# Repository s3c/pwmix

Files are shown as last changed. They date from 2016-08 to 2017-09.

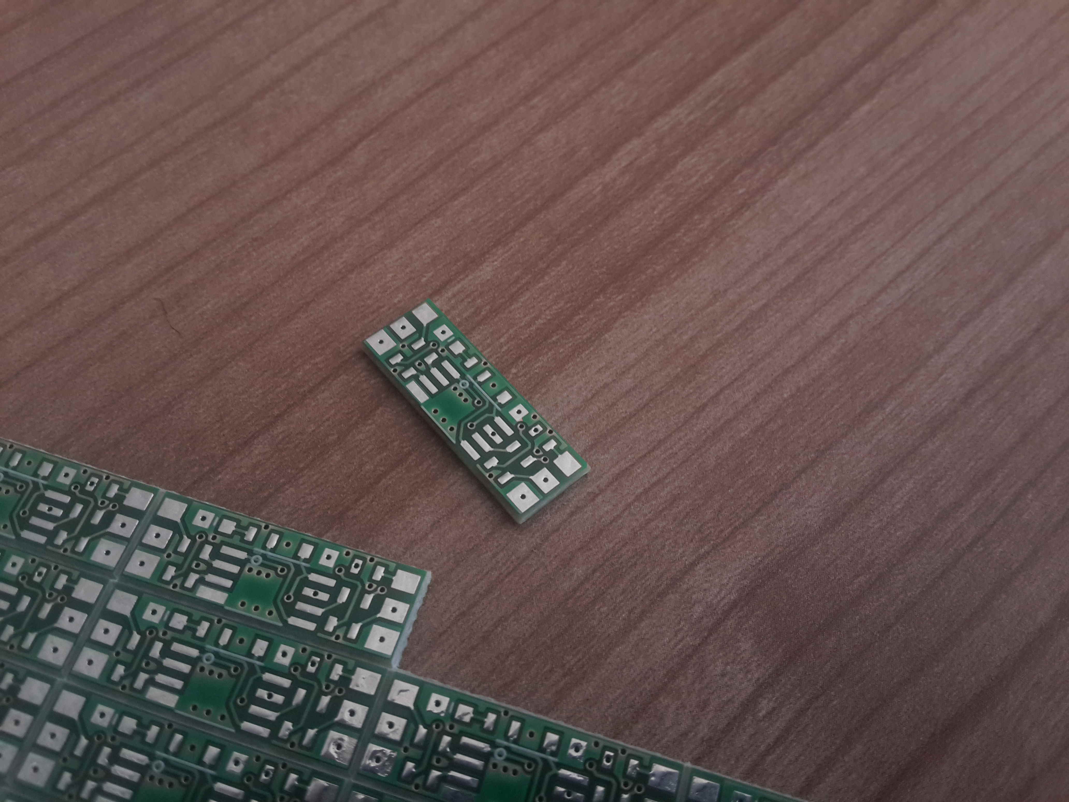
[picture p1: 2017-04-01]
pictures/IMG_20160907_095543.jpg

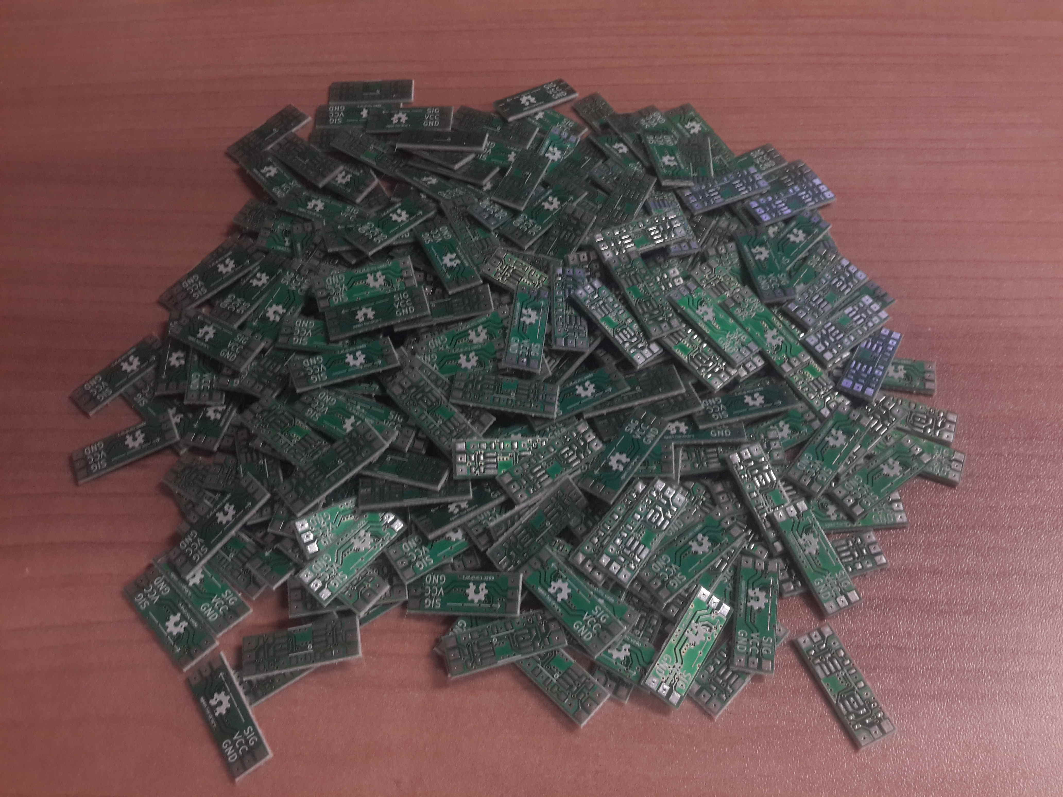
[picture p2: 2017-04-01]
pictures/IMG_20160907_113401.jpg

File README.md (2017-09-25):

The pwmix project is a small hardware device that can alter PWM/PPM signals generated by common hobby remote controls. This allows enabling mixing for cheap RC transmitters, or where the receiver applies some mechanism that isn't desired. It is based on the Attiny85 but smaller micro controllers like the Attiny25 can  be used, you'll need a pretty steady hand to make it fit on the edge of the larger footprint though. 

The unit supports two inputs and two outputs, although these are identical and can potentially be used otherwise. With the micro controller facing upwards, the top left channel is input channel one, the bottom left channel is input two, the bottom right channel is output one, and the top right channel is output two. By convention, input one is considered the main input, and input two is considered the modulating input.

Since the Attiny85 has an inaccurate internal timer, rather than adding a crystal the unit does a clock sync to sync with the receiver. This is done by adjusting the internal clock using a binary search at startup, to match the expected pulse length with what is received. This is done on input channel one, and the expected value differs between code features.

The project was created with the following in mind:

* (DONE) Differential drive mixing - the main input takes a motor drive, while the second takes a servo turning signal. These are mixed together to output two motor drive signals mixed to provide differential drive. This allows the use of two motors to drive and steer, as opposed to a motor and a servo. Initial sync should be at mid stick (1.5mS PWM pulse)
* Servo limiting (planned) - the main input takes a servo input, while the optional second input takes a calibration servo signal. If the second signal is present, the minimum and maximum values are stored and saved in EEPROM. The output signals are mirrored and will never exeed the stored limits. To set the limits plug in both signals and vary the second signal between min/max. The input signal is scaled so full input deflection gives full limited output deflection. Initial sync should be at low stick (1mS PWM pulse)
* Fake Nitrous oxide (planned) - the main input takes a motor drive, while the second takes a enable signal. If the enable signal is greater than 3/4 full deflection, the mirrored outputs (following the motor drive signal) are allowed to swing to greater than 50%, if not, the output signals are limited to 50%. When this enable trigger is active, a timer decrements a 30 second limit, which limits the motor to 50% when depleted. This creates a fake boost mechanism, which gives a more dynamic nature to racing. Initial sync should be at mid stick (1.5mS PWM pulse)
* (DONE) PPM to PWM converter - Each board strips off the first two PPM channels and outputs them as PWM, then passes the remaining PPM signal along. This allows daisy chaining the PPM signal along the body of the plane so you only need to run one wire from the receiver and still be able to control all servos/motors, etc.

Known issues (Differential drive mixing):
* There seems to be a dead band/jitter of around 50uS for small values on input two in one direction, this also seems to reflect more on output one than output two for some reason. I don't really know why this is happening, I've confirmed that there is a tiny dead band/jitter on the input channel, but insignificant compared to the output. The inputs/outputs aren't handled differently in any way so some weird race condition is in play here. The most likely scenario is that the edge trigger interrupt fires just before the compare match timer, so the timer interrupt only fires after the edge has been processed, creating a dead band region. The ideal fix for this would be to use the compare match module to automatically turn off the output pins, but the hardware doesn't allow this, as the output pins aren't assigned to the compare match pins. I'll fix this if there's ever another revision. **Update: Ok, I managed to confirm that this was the problem, and I fixed the issue by making the pin change ISR non-blocking and adding a flag to avoid re-entry if another pin change occured. We still have some jitter but that's to be expected considering all the overhead and no crystal. The above fix would still be better though**

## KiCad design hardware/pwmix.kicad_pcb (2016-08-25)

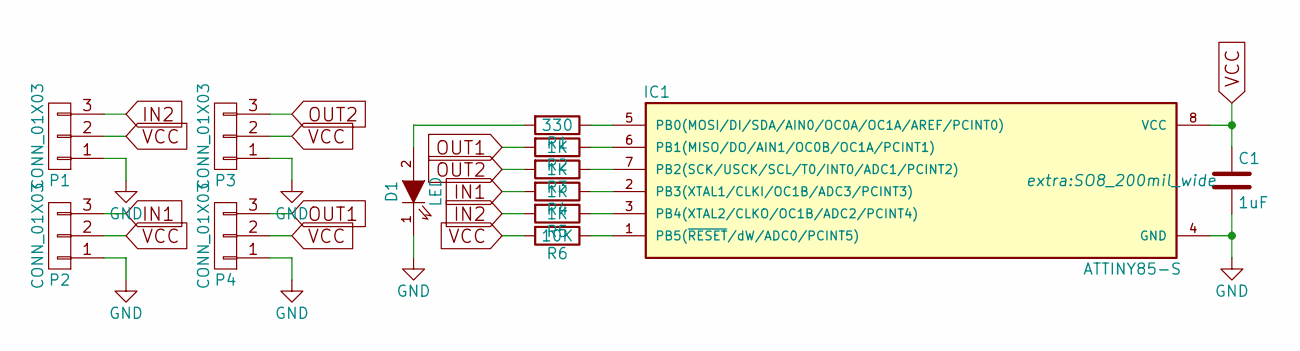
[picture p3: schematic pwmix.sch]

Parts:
C1: 1uF; C_0805
D1: LED; LED_0805
IC1: ATTINY85-S; SO8_200mil_wide
P1, P2, P3, P4: CONN_01X03; Pin_Header_Angled_1x03
R1: 330; R_0805
R2, R3, R4, R5: 1K; R_0805
R6: 10K; R_0805

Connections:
GND: C1.2, D1.1 (K), IC1.4 (GND), P1.1, P2.1, P3.1, P4.1
IN1: P2.3, R4.2
IN2: P1.3, R5.2
unnamed: D1.2 (A), R1.2
unnamed: IC1.1 (PB5(~RESET~/dW/ADC0/PCINT5)), R6.1
unnamed: IC1.2 (PB3(XTAL1/CLKI/OC1B/ADC3/PCINT3)), R4.1
unnamed: IC1.3 (PB4(XTAL2/CLKO/OC1B/ADC2/PCINT4)), R5.1
unnamed: IC1.5 (PB0(MOSI/DI/SDA/AIN0/OC0A/OC1A/AREF/PCI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), R1.1
unnamed: IC1.6 (PB1(MISO/DO/AIN1/OC0B/OC1A/PCINT1)), R2.1
unnamed: IC1.7 (PB2(SCK/USCK/SCL/T0/INT0/ADC1/PCINT2)), R3.1
OUT1: P4.3, R2.2
OUT2: P3.3, R3.2
VCC: C1.1, IC1.8 (VCC), P1.2, P2.2, P3.2, P4.2, R6.2

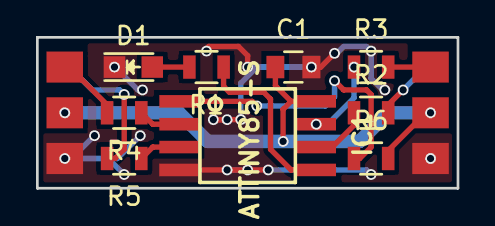
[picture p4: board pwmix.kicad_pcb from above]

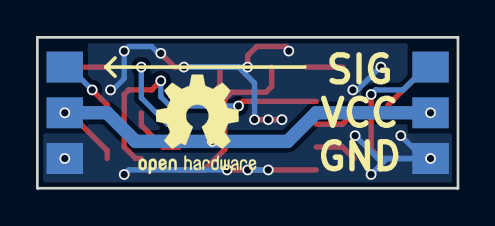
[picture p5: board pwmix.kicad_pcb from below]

Board: 2 copper layers, 23.4 x 8.4 mm, 13 parts (2 on the bottom side), 13 nets.

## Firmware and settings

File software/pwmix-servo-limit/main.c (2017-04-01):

/*
 * pwmix2.c
 *
 * Created: 9/10/2016 7:29:07 AM
 * Author : User
 */ 

//Prog
//3 - Aux	->	Ch1
//2 - Th	->	Ch2
//1 - St	->	NC

//Use
//3 - Aux	->	Ch1
//2 - Th	->	NC
//1 - St	->	NC

#define F_CPU 8000000UL

#include <avr/io.h>
#include <avr/interrupt.h>
#include <util/delay.h>
#include <avr/eeprom.h>
#include "main.h"

volatile int16_t lastPulseValI16A[2]; //Stores the last pulse received for each channel
volatile int16_t mixPulseValI16A[2]; //Stores the output pulse after mixing
volatile uint8_t inputStateUI8A[2]; //Stores the state of each channel
volatile uint8_t minServoValUI8; //Minimum value servo is allowed to take
volatile uint8_t maxServoValUI8; //Maximum value servo is allowed to take
volatile uint8_t saveCounterUI8; //Prohibit saving until this counter reaches certain value
volatile uint8_t flagsUI8; //Stores sync flags 

ISR(TIM0_COMPA_vect){ //Turn off channel one output on compare match, have to do this manually since the pins weren't assigned correctly
	PORTB &= ~_BV(OUT_CHANNEL_ONE);
}

ISR(TIM1_COMPA_vect){ //Turn off channel two output on compare match, have to do this manually since the pins weren't assigned correctly
	PORTB &= ~_BV(OUT_CHANNEL_TWO);
}

void saveControl(void){
	//Todo: if in config mode, both channels are idle, new boundary received, and save counter is high enough, save and pulse led, reset counter and flags
	
	if((flagsUI8 & FLAGS_CH_TWO_RECV) && (inputStateUI8A[CHANNEL_ONE] == STATE_IDLE) && (inputStateUI8A[CHANNEL_TWO] == STATE_IDLE)){
		
		
	}
}

ISR(TIM0_OVF_vect){
	//flagsUI8 |= FLAGS_CH_ONE_RECV;
	if(inputStateUI8A[CHANNEL_ONE] == STATE_ACTIVE) //If we had an overflow before the pulse ended
		lastPulseValI16A[CHANNEL_ONE] = PWM_MAX; //Just save the value as longest valid pulse length
	inputStateUI8A[CHANNEL_ONE] = STATE_IDLE;
	PORTB &= ~_BV(OUT_CHANNEL_ONE); //Should never be needed
	TCCR0B = 0; //Disable TIMR0
	saveControl(); //Check this for both input channels, since we don't want to cause an EEPROM write lock while input is active
}

ISR(TIM1_OVF_vect){
	//flagsUI8 |= FLAGS_CH_TWO_RECV;
	if(inputStateUI8A[CHANNEL_TWO] == STATE_ACTIVE) //If we had an overflow before the pulse ended
		lastPulseValI16A[CHANNEL_TWO] = PWM_MAX; //Just save the value as longest valid pulse length
	inputStateUI8A[CHANNEL_TWO] = STATE_IDLE;
	PORTB &= ~_BV(OUT_CHANNEL_TWO); //Should never be needed
	TCCR1 = 0; //Disable TIMR1
	saveControl(); //Check this for both input channels, since we don't want to cause an EEPROM write lock while input is active
}

ISR(PCINT0_vect, ISR_NOBLOCK){ //Executed in input pin change
	uint8_t channelVarUI8, channelTmpUI8;
	
	if(flagsUI8 & FLAGS_PIN_CHANGE)
		return;
	flagsUI8 |= FLAGS_PIN_CHANGE;
	
	for(channelVarUI8 = CHANNEL_ONE; channelVarUI8 <= CHANNEL_TWO; channelVarUI8++){ //Check both input channels, since pin change int doesn't tell us which pin changed
		switch(inputStateUI8A[channelVarUI8]){
			case STATE_IDLE:
				if(PINB & _BV((channelVarUI8 == CHANNEL_ONE)?IN_CHANNEL_ONE:IN_CHANNEL_TWO)){ //If state idle and input signal high
					inputStateUI8A[channelVarUI8] = STATE_ACTIVE;
					if(flagsUI8 & FLAGS_CH_TWO_RECV){ //if sync mode output current ch2 value
						mixPulseValI16A[CHANNEL_ONE] = lastPulseValI16A[CHANNEL_TWO];
						mixPulseValI16A[CHANNEL_TWO] = PWM_MIDDLE - (PWM_MIDDLE - lastPulseValI16A[CHANNEL_TWO]);
					}else{ //if normal mode, scale max output to ch2 presets
						mixPulseValI16A[CHANNEL_ONE] = lastPulseValI16A[CHANNEL_ONE];
						mixPulseValI16A[CHANNEL_TWO] = PWM_MIDDLE - (PWM_MIDDLE - lastPulseValI16A[CHANNEL_ONE]);
					}
					for(channelTmpUI8 = CHANNEL_ONE; channelTmpUI8 <= CHANNEL_TWO; channelTmpUI8++){ //Make sure the mixed values are within reasonable limits
						if(mixPulseValI16A[channelTmpUI8] > maxServoValUI8)
							mixPulseValI16A[channelTmpUI8] = maxServoValUI8;
						if(mixPulseValI16A[channelTmpUI8] < minServoValUI8)
							mixPulseValI16A[channelTmpUI8] = minServoValUI8;
					}
					if(channelVarUI8 == CHANNEL_ONE){
						OCR0A = mixPulseValI16A[CHANNEL_ONE]; //Set compare match to stop output pulse
						TCNT0 = 0; //Reset TMR0 				
						GTCCR |= _BV(PSR0); //Reset TMR0 prescaler
						TCCR0B |= _BV(CS01) | _BV(CS00); //Start TMR0 with 64 prescaler
						if(flagsUI8 & FLAGS_SYNC_DONE)
							PORTB |= _BV(OUT_CHANNEL_ONE); //Set channel output high
					}else{
						OCR1A = mixPulseValI16A[CHANNEL_TWO]; //Set compare match to stop output pulse
						TCNT1 = 0; //Reset TMR1 
						GTCCR |= _BV(PSR1); //Reset TMR1 prescaler
						TCCR1 |= _BV(CS12) | _BV(CS11) | _BV(CS10); //Start TMR1 with 64 prescaler
						if(flagsUI8 & FLAGS_SYNC_DONE)
							PORTB |= _BV(OUT_CHANNEL_TWO); //Set channel output high
					}
				}
				break;
			case STATE_ACTIVE:
				if(!(PINB & _BV((channelVarUI8 == CHANNEL_ONE)?IN_CHANNEL_ONE:IN_CHANNEL_TWO))){ //If state active and input signal low
					inputStateUI8A[channelVarUI8] = STATE_IDLE;
					if(channelVarUI8 == CHANNEL_ONE){
						lastPulseValI16A[CHANNEL_ONE] = TCNT0; //Save the length of last pulse
						flagsUI8 |= FLAGS_CH_ONE_RECV; //Mark that we received a new pulse (for sync)
					}else{
						lastPulseValI16A[CHANNEL_TWO] = TCNT1; //Save the length of last pulse
						flagsUI8 |= FLAGS_CH_TWO_RECV; //Mark that we received a new pulse (for sync)
						if(flagsUI8 & FLAGS_SYNC_DONE){
							if(lastPulseValI16A[CHANNEL_TWO] < minServoValUI8){
								minServoValUI8 = lastPulseValI16A[CHANNEL_TWO];
								flagsUI8 |= FLAGS_LIMIT_CHANGE;
								saveCounterUI8 = 0;
							}else if(lastPulseValI16A[CHANNEL_TWO] > maxServoValUI8){
								maxServoValUI8 = lastPulseValI16A[CHANNEL_TWO];
								flagsUI8 |= FLAGS_LIMIT_CHANGE;
								saveCounterUI8 = 0; 
							}else if(saveCounterUI8 < LIMIT_CHANGE_SAVE)
									saveCounterUI8++;
						}
					}
				}
				break;
		}
	}
	
	flagsUI8 &= ~FLAGS_PIN_CHANGE;
}

void inline waitNextPulse(void){
	flagsUI8 &= ~FLAGS_CH_ONE_RECV; //First pulse might be incomplete do to changing clock mid pulse, so disregard
	while(!(flagsUI8 & FLAGS_CH_ONE_RECV)); //Wait till we have a new pulse length
	flagsUI8 &= ~FLAGS_CH_ONE_RECV; //Redo and get a valid pulse length
	while(!(flagsUI8 & FLAGS_CH_ONE_RECV)); //Wait till pulse is done
}

void clockSync(void){ //Sync clock to receiver, assuming first couple of pulses from receiver is at mid stick, ie, 1.5mS
	int16_t curDevI16, minDevI16 = INT16_MAX;
	uint8_t stepValueUI8 = 64, trialValueUI8 = _BV(7), minTrialValueUI8 = UINT8_MAX, tmpTrialValueUI8;
	
	do{ //Binary search over 7 bits of OSCCAL, bit 7 is high range bit so we skip it
		OSCCAL = trialValueUI8 + stepValueUI8;
		waitNextPulse();
		if(lastPulseValI16A[CHANNEL_ONE] < PWM_SYNC)
			trialValueUI8 += stepValueUI8;
		stepValueUI8 >>= 1;
	}while(stepValueUI8);
	
	for(tmpTrialValueUI8 = trialValueUI8 - 1; tmpTrialValueUI8 <= trialValueUI8 + 1; tmpTrialValueUI8++){ //Local search to identify closest match
		OSCCAL = tmpTrialValueUI8;
		waitNextPulse();
		curDevI16 = abs(lastPulseValI16A[CHANNEL_ONE] - PWM_SYNC);
		if(curDevI16 < minDevI16){
			minDevI16 = curDevI16;
			minTrialValueUI8 = tmpTrialValueUI8;
		}
	}

	OSCCAL = minTrialValueUI8; //Set closest clock value
	flagsUI8 |= FLAGS_SYNC_DONE; //Set sync as complete, so output module can start generating pulses
	PORTB |= _BV(OUT_CHANNEL_LED); //Turn on LED to notify setup complete
}

void loadSavedLimits(void){
	
	minServoValUI8 = eeprom_read_byte(EEPROM_ADDR_MIN);
	maxServoValUI8 = eeprom_read_byte(EEPROM_ADDR_MAX);
	
	if(minServoValUI8 == 0xFF || maxServoValUI8 == 0xFF){
		minServoValUI8 = PWM_MIN;
		maxServoValUI8 = PWM_MAX;
	}
}

void saveNewLimits(void){
	eeprom_write_byte(EEPROM_ADDR_MIN, minServoValUI8);
	eeprom_write_byte(EEPROM_ADDR_MAX, maxServoValUI8);
}

void init(void){
	
	DDRB |= _BV(OUT_CHANNEL_ONE) | _BV(OUT_CHANNEL_TWO) | _BV(OUT_CHANNEL_LED); //Set output channels as outputs
	PORTB |= _BV(IN_CHANNEL_ONE) | _BV(IN_CHANNEL_TWO); //Enable pull-ups for input channels
	
	lastPulseValI16A[CHANNEL_ONE] = lastPulseValI16A[CHANNEL_TWO] = PWM_MAX+1; //Clear last pules length values initially
	mixPulseValI16A[CHANNEL_ONE] = mixPulseValI16A[CHANNEL_TWO] = PWM_MIDDLE; //Set initial mixing output values
	inputStateUI8A[CHANNEL_ONE] = inputStateUI8A[CHANNEL_TWO] = STATE_IDLE; //Set start states to idle
	flagsUI8 = FLAGS_NONE; //Blank initial flags
	
	TIMSK |= _BV(OCIE0A) | _BV(TOIE0) | _BV(OCIE1A) | _BV(TOIE1); //TMR0/1 Interrupt on compare match and overflow
	
	PCMSK |= _BV(IN_CHANNEL_ONE) | _BV(IN_CHANNEL_TWO); //Enable pin change interrupts on input pins
	GIMSK |= _BV(PCIE); //Enable pin change interrupts globally
	
	sei();
}

int main(void){
	
	_delay_ms(100); //Allow everything to start up
	
	init(); //Initialize all peripherals and variables
	clockSync(); //Perform the clock sync, as INT RC OSC is pretty crap, assume receiver is correct

	if(flagsUI8 & FLAGS_CH_TWO_RECV)
		minServoValUI8 = maxServoValUI8 = PWM_MIDDLE;
	else
		loadSavedLimits();

	while(1){

	}
}

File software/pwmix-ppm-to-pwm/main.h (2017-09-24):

/*
 * main.h
 *
 * Created: 9/8/2016 4:50:35 AM
 *  Author: User
 */ 

#ifndef MAIN_H_
#define MAIN_H_

#define STATE_IDLE				0
#define STATE_WAIT				1
#define STATE_PULSE_1_START		2
#define STATE_PULSE_1_MID		3
#define STATE_PULSE_2_START		4
#define STATE_PULSE_2_MID		5

#define IN_CHANNEL_PPM			PB3

#define OUT_CHANNEL_ONE			PB1
#define OUT_CHANNEL_TWO			PB2
#define OUT_CHANNEL_LED			PB0
#define OUT_CHANNEL_PPM			PB4

#endif /* MAIN_H_ */

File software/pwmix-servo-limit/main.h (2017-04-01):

/*
 * main.h
 *
 * Created: 9/8/2016 4:50:35 AM
 *  Author: User
 */ 

#ifndef MAIN_H_
#define MAIN_H_

#include <avr/io.h>

#define abs(x) (((x)>0)?(x):(-x))

#define FLAGS_NONE			0
#define FLAGS_CH_ONE_RECV   1
#define FLAGS_CH_TWO_RECV   2
#define FLAGS_SYNC_DONE		4
#define FLAGS_PIN_CHANGE	8
#define FLAGS_PROG_nNORM	16
#define FLAGS_LIMIT_CHANGE	32
#define FLAGS_PULSE_LED		64

#define CHANNEL_ONE			0
#define CHANNEL_TWO			1

#define PWM_MIN				125
#define PWM_MIDDLE			188
#define PWM_MAX				250
#define PWM_SYNC			PWM_MIN

#define LIMIT_CHANGE_SAVE	50

#define STATE_IDLE			0
#define STATE_ACTIVE		1

#define EEPROM_ADDR_MIN		(uint8_t *) 0
#define EEPROM_ADDR_MAX		(uint8_t *) 1

#define IN_CHANNEL_ONE		PB3
#define IN_CHANNEL_TWO		PB4

#define OUT_CHANNEL_ONE		PB1
#define OUT_CHANNEL_TWO		PB2
#define OUT_CHANNEL_LED		PB0

#endif /* MAIN_H_ */

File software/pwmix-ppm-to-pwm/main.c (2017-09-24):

/*
 * pwmix2.c
 *
 * Created: 9/10/2016 7:29:07 AM
 * Author : User
 */ 

#define F_CPU 8000000UL

#include <avr/io.h>
#include <avr/interrupt.h>
#include "main.h"

volatile uint8_t systemStateUI8; //Stores the current state

void copy_output_input(void){
	if(PINB & _BV(IN_CHANNEL_PPM))
		PORTB |= _BV(OUT_CHANNEL_PPM);
	else
		PORTB &= ~_BV(OUT_CHANNEL_PPM);
}


ISR(TIM1_OVF_vect){
	systemStateUI8 = STATE_WAIT;
	PORTB ^= _BV(OUT_CHANNEL_LED);
	TCCR1 = 0; //Disable TMR1
}

ISR(PCINT0_vect){

	TCNT1 = 0; //Reset TMR1
	GTCCR |= _BV(PSR1); //Reset TMR1 prescaler

	switch(systemStateUI8){
		case(STATE_IDLE):
			copy_output_input();
			break;
		case(STATE_WAIT):
			systemStateUI8 = STATE_PULSE_1_START;
			PORTB |= _BV(OUT_CHANNEL_ONE);
			break;
		case(STATE_PULSE_1_START):
			systemStateUI8 = STATE_PULSE_1_MID;
			break;
		case(STATE_PULSE_1_MID):
			systemStateUI8 = STATE_PULSE_2_START;
			PORTB &= ~_BV(OUT_CHANNEL_ONE);
			PORTB |= _BV(OUT_CHANNEL_TWO);
			break;
		case(STATE_PULSE_2_START):
			systemStateUI8 = STATE_PULSE_2_MID;
			break;
		case(STATE_PULSE_2_MID):
			systemStateUI8 = STATE_IDLE;
			PORTB &= ~_BV(OUT_CHANNEL_TWO);
			copy_output_input();
			TCCR1 |= _BV(CS13); //TMR1 128 prescaler
			break;
	}
}

void init(void){
	
	systemStateUI8 = STATE_IDLE; //Set start state to idle
	
	DDRB |= _BV(OUT_CHANNEL_PPM) | _BV(OUT_CHANNEL_ONE) | _BV(OUT_CHANNEL_TWO) | _BV(OUT_CHANNEL_LED); //Set output channels as outputs
	PORTB |= _BV(IN_CHANNEL_PPM); //Enable pull-ups for input channel
	copy_output_input();
	
	TIMSK |= _BV(TOIE1); //TMR1 Interrupt on overflow
	TCCR1 |= _BV(CS13); //TMR1 128 prescaler
	
	PCMSK |= _BV(IN_CHANNEL_PPM); //Enable pin change interrupts on input pin
	GIMSK |= _BV(PCIE); //Enable pin change interrupts globally
	
	sei();
}

int main(void){
	
	init(); //Initialize all peripherals and variables

	while(1){}
}

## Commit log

2016-08-24 Redid layout, as attiny85 footprint in kicad is way too small
    [pwmix.drl, pwmix.gbl, pwmix.gbo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]
2016-08-25 Regenerated and submitted gerbers
    [pwmix.kicad_pcb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]
2016-09-11 First version fail, clock accuracy issues, going to redo with sync
    [main.c, main.h]
2016-09-11 Jitter is way better now, was a rounding error and unsigned to signed conversion, still some jitter on the one channel, which makes no sense since they should be equal
    [main.c, main.h]
2016-09-17 Fixed the jitter/dead band issue
    [main.c, main.h]
2017-04-01 Ehh, dunno, loads of stuff
    [pwmix.kicad_pcb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]
2017-09-24 Added PPM to PWM converter
